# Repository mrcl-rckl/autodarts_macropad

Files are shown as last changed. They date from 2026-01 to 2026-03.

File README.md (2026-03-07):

<div align="center">
    3D-Modell
  
  <h1>🎯 Macropad for Autodarts</h1>
  <p><b>✨ The ultimate DIY wireless companion for your Autodarts setup ✨</b></p>
  <p><i>A custom 12-key controller designed for seamless darts tracking.</i></p>

  <p>
    The Macropad for Autodarts is a wireless DIY controller featuring 12 mechanical keys, specifically designed for comfortable operation of the Autodarts software directly from the oche. It provides instant access to functions such as undoing throws, switching cameras, triggering chat macros, or calling the AI referee. Utilizing smart ZMK firmware, it features multi-tap functions and dedicated correction layers optimized for the Autodarts Tools extension, while offering an impressive battery life of about six weeks via Bluetooth.
  </p>

  <p>
    
    
    
  </p>

  <p>
    <a href="#features-en">🚀 Features</a> •
    <a href="#manual-en">📖 Manual</a> •
    <a href="#diagrams-en">🗺️ Wiring & Pinout</a> •
    <a href="#keymap-en">🎹 Keymap & Layers</a> •
    <a href="#bom-en">📦 BOM</a> •
    <a href="#operation-en">💡 Troubleshooting</a> •
    <a href="#support-en">☕ Support</a>
  </p>
</div>

<hr />

<h2 id="features-en">🚀 Key Features</h2>
<ul>
  <li><b>📶 True Wireless:</b> Low-energy Bluetooth 5.0 connectivity via the nRF52840 controller for a cable-free oche. 🎯</li>
  <li><b>🔋 Massive Battery Life:</b> Operates for up to <b>6 weeks</b> on a single charge. The integrated deep-sleep mode further preserves battery life. ⚡</li>
  <li><b>🧠 Smart ZMK Layers:</b> Features tap-dance capabilities (e.g., single tap for correction, double tap for camera switch) to map far more than 12 functions to the board.</li>
  <li><b>🔢 Autodarts Tools Integration:</b> A dedicated numpad layer instantly activates for score corrections, sends your input, and automatically snaps back to your game layout. </li>
  <li><b>⌨️ Superior Tactile Feedback:</b> 12 mechanical Gateron G Pro 3.0 switches provide a high-quality actuation point for reliable inputs. ⌨️</li>
  <li><b>☁️ Cloud Configuration:</b> Customize your keymap directly in the browser via GitHub Actions—no local coding environment required. ☁️</li>
</ul>

<hr />

<h2 id="manual-en">📖 Comprehensive Manual</h2>
<p>
  This repository includes a <b>detailed 32-page PDF instruction manual</b>. It covers the entire process: from optimized 3D printing settings and complex matrix soldering to flashing the ZMK firmware and customized key mapping.
  <br><br>
  👉 <b>View the Instructions here:</b> <a href="https://github.com/mrcl-rckl/autodarts_macropad/blob/main/instructions/0_EN_Instructions.pdf">0_EN_Instructions.pdf</a>
  <br>
  👉 <b>3D Models on Printables:</b> <a href="https://www.printables.com/model/1576041-autodarts-macropad">Printables.com</a>
  <br>
  👉 <b>3D Models on MakerWorld:</b> <a href="https://makerworld.com/de/models/2319788-autodarts-macropad">MakerWorld.com</a>
</p>

<hr />

<h2 id="bom-en">📦 Bill of Materials (BOM)</h2>
<p>This project is designed for experienced makers and involves 3D printing, component assembly, and precision soldering. 🛠️</p>
<table>
  <thead>
    <tr>
      <th>Qty</th>
      <th>Component 🛒</th>
      <th>Source 🔗</th>
    </tr>
  </thead>
  <tbody>
    <tr>
      <td>12x</td>
      <td><b>Gateron G Pro 3.0 Switches</b></td>
      <td><a href="https://de.aliexpress.com/item/1005007052507996.html">AliExpress</a></td>
    </tr>
    <tr>
      <td>1x</td>
      <td><b>nRF52840 Developer Board (SuperMini)</b></td>
      <td><a href="https://de.aliexpress.com/item/1005008664621573.html">AliExpress</a></td>
    </tr>
    <tr>
      <td>1x</td>
      <td><b>500mAh LiPo Battery (503030)</b></td>
      <td><a href="https://de.aliexpress.com/item/1005007964712378.html">AliExpress</a></td>
    </tr>
    <tr>
      <td>12x</td>
      <td><b>1N4148 Diodes</b></td>
      <td><a href="https://de.aliexpress.com/item/1005006208000285.html">AliExpress</a></td>
    </tr>
    <tr>
      <td>16x</td>
      <td><b>Jumper Wires Female (20-30cm)</b></td>
      <td><a href="https://de.aliexpress.com/item/1005007046465880.html">AliExpress</a></td>
    </tr>
    <tr>
      <td>1x</td>
      <td><b>Toggle Switch (MTS-101)</b></td>
      <td><a href="https://de.aliexpress.com/item/1005009744920784.html">AliExpress</a></td>
    </tr>
    <tr>
      <td>1x</td>
      <td><b>ASUS USB-BT500 Bluetooth Dongle</b></td>
      <td><a href="https://www.cyberport.de/pc-und-zubehoer/netzwerk/bluetooth/asus/pdp/4e18-007/asus-usb-bt500-bluetooth-5-0-usb-adapter.html">Cyberport</a></td>
    </tr>
  </tbody>
</table>

<h3>🛠️ Required Tools & Additional Materials</h3>
<ul>
  <li>USB-C charging cable</li>
  <li>Soldering iron & Solder wire</li>
  <li>Hot air gun or lighter (for insulation)</li>
  <li>Heat shrinks & side cutters</li>
  <li>Pliers & wire stripping tool</li>
  <li>Super glue (for mounting logos)</li>
  <li>Filament (PLA or PETG - 2 colors recommended)</li>
</ul>

<hr />

<h2 id="diagrams-en">🗺️ Wiring Diagram & Pinout</h2>
<div align="center">
  <h3>🛠️ Wiring Diagram</h3>
  Wiring Diagram
  <br><br>
  <h3>🔌 Controller Pinout</h3>
  Pin Diagram
</div>

<hr />

<h2 id="keymap-en">🎹 Default Key Assignment & Layers</h2>
<p>The layout is fully optimized for the Autodarts web interface commands. Through smart ZMK firmware programming, the 12 physical keys access three different functional layers: 🎯</p>

<ul>
  <li><b>Layer 0 (Main):</b> Game controls (Start/Stop, Refresh, AI, Undo, Next, Mouse Click). Multi-tap keys let you send chat macros (tap vs. double-tap). Bottom row selects a dart for correction (1x tap) or switches cameras (2x tap).</li>
  <li><b>Layer 1 (Admin/BT):</b> Activated by double-tapping <b>Undo + Next</b> simultaneously. Stays active for 5 seconds to switch/clear Bluetooth profiles, restart, or enter bootloader mode.</li>
  <li><b>Layer 2 (Numpad):</b> Opens automatically when selecting a dart. Matches the <i>Autodarts Tools</i> extension numpad (1-9, Miss, 25, Bull). <b>Smart Exit:</b> Tapping any score automatically returns you to Layer 0. Holding any key for 1 second cancels the correction and returns to Layer 0 without sending a score.</li>
</ul>

<div align="center">
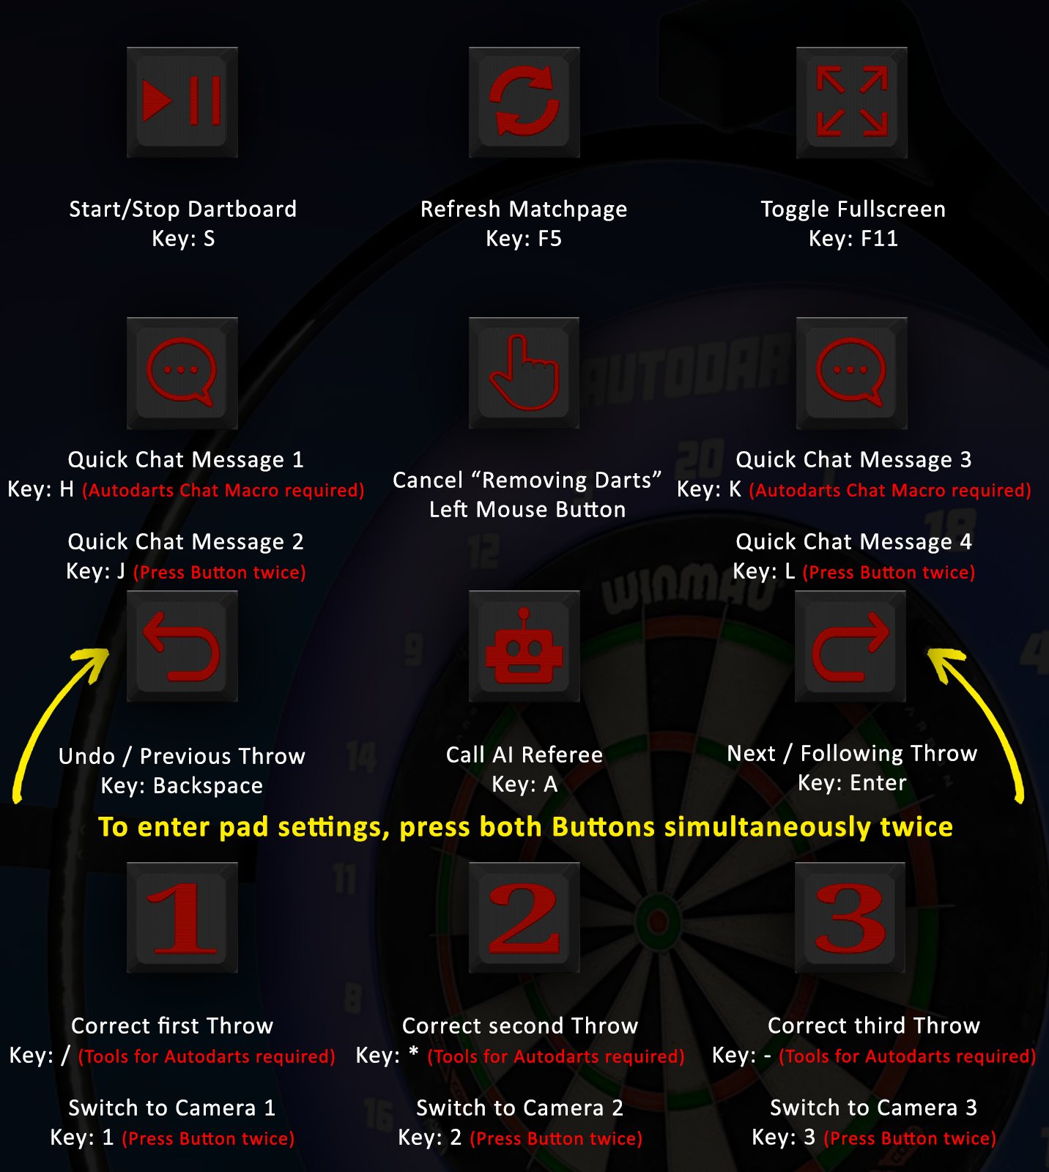
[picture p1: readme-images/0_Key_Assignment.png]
Keymap Assignment
  
</div>

<div align="center">
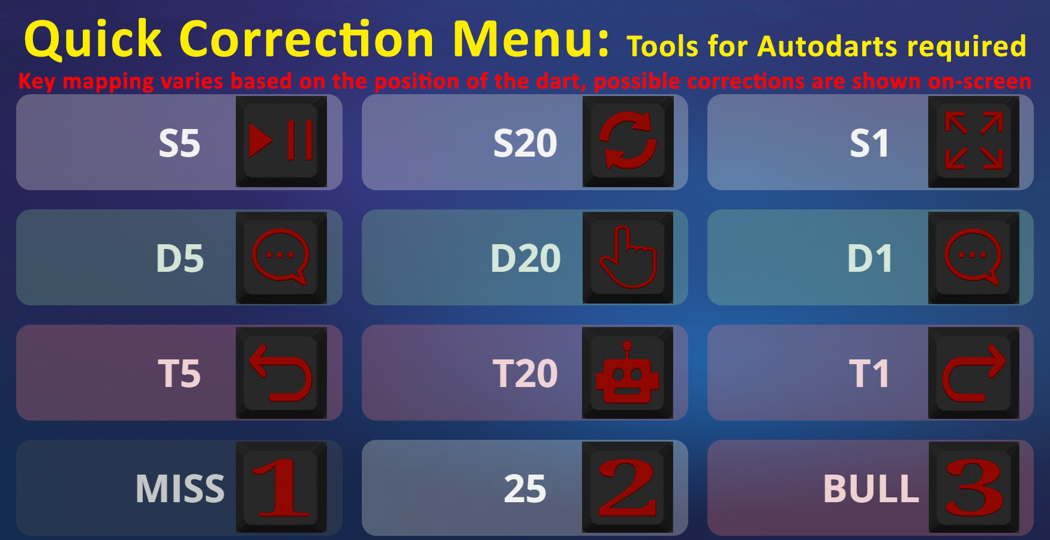
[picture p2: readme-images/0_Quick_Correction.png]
Quick Correction
  
</div>

<div align="center">
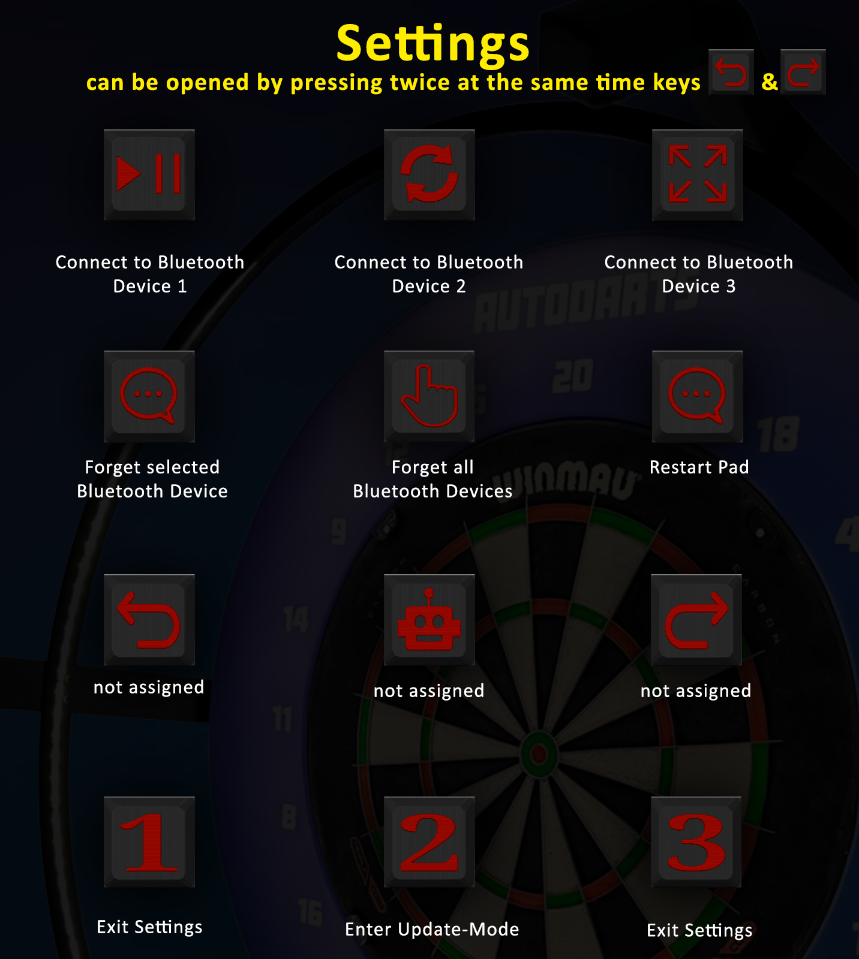
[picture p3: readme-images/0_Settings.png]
Settings
  
</div>

<br>

<hr />

<h2 id="operation-en">💡 Operation & Troubleshooting</h2>
<ul>
  <li><b>Charging:</b> The physical toggle switch <b>MUST be in the ON position</b> to charge the battery via USB-C. 🔌</li>
  <li><b>Admin Mode & Bluetooth:</b> To switch or clear Bluetooth profiles, double-tap <b>[Undo] + [Next]</b> simultaneously to enter the Admin Layer (active for 5s). 🔄</li>
  <li><b>Cancel Correction:</b> If you accidentally enter the Numpad layer, press and hold ANY key for 1 second to cancel and return to your game. 🔙</li>
  <li><b>Bootloader Mode:</b> If the software bootloader command fails, bridge the <b>GND</b> and <b>RST</b> pins twice quickly with tweezers while connected to the PC to flash a new firmware. 💾</li>
  <li><b>Input Focus:</b> Ensure the browser window is "in focus" (clicked) for Autodarts to register key presses. 🎯</li>
</ul>

<hr />

<h2 id="support-en">☕ Support</h2>
<p align="left">
  If this project helped you hit the bullseye, consider supporting my work! 🎯☕
  <br><br>
  <a href="https://www.buymeacoffee.com/mrcl_rckl">
    Buy Me A Coffee
  </a>
</p>

<hr />
<br><br>

<br><br>
<hr />

<div align="center">
  <h1>🎯 Zusatztastatur für Autodarts</h1>
  <p><b>✨ Der ultimative kabellose Begleiter für dein Autodarts-Setup – Marke Eigenbau ✨</b></p>
  <p><i>Ein maßgeschneidertes 12-Tasten-Steuergerät für die professionelle Wurferfassung am Oche.</i></p>

  <p>
    Das Macropad für Autodarts ist ein kabelloses DIY-Steuergerät mit 12 mechanischen Tasten, das speziell für die komfortable Bedienung der Autodarts-Software direkt am Oche entwickelt wurde. Es ermöglicht den blitzschnellen Zugriff auf Funktionen wie Wurfrücknahme, Kamerawechsel, Chat-Makros oder den KI-Schiedsrichter. Dank intelligenter ZMK-Firmware bietet das Pad smarte Mehrfachklick-Funktionen sowie eine perfekt auf die Autodarts Tools angepasste Numpad-Ebene und erreicht dabei über Bluetooth eine beachtliche Akkulaufzeit von etwa sechs Wochen.
  </p>

  <p>
    
    
    
  </p>

  <p>
    <a href="#features-de">🚀 Funktionen</a> •
    <a href="#manual-de">📖 Anleitung</a> •
    <a href="#diagrams-de">🗺️ Schaltplan & Pinbelegung</a> •
    <a href="#keymap-de">🎹 Tastenbelegung & Ebenen</a> •
    <a href="#bom-de">📦 Stückliste</a> •
    <a href="#operation-de">💡 Fehlerbehebung</a> •
    <a href="#support-de">☕ Unterstützung</a>
  </p>
</div>

<hr />

<h2 id="features-de">🚀 Hauptmerkmale</h2>
<ul>
  <li><b>📶 Vollkommen Kabellos:</b> Dank Bluetooth 5.0 und dem nRF52840-Steuermodul bleibt dein Abwurfbereich frei von Kabeln. 🎯</li>
  <li><b>🔋 Enorme Akkulaufzeit:</b> Eine einzige Ladung hält bei normaler Nutzung bis zu <b>6 Wochen</b>. Der integrierte Tiefschlafmodus schont die Batterie zusätzlich. ⚡</li>
  <li><b>🧠 Smarte ZMK-Ebenen:</b> Dank Tap-Dance-Funktion (z.B. 1x Tippen für Dart-Korrektur, 2x Tippen für Kamerawechsel) lassen sich weit mehr als 12 Funktionen steuern.</li>
  <li><b>🔢 Autodarts Tools Integration:</b> Eine spezielle Numpad-Ebene für die Erweiterung öffnet sich automatisch, sendet den gewählten Score und springt selbstständig ins Hauptmenü zurück.</li>
  <li><b>⌨️ Hochwertiger Druckpunkt:</b> 12 mechanische Gateron G Pro 3.0 Schalter bieten ein erstklassiges haptisches Feedback und garantieren eine zuverlässige Bedienung. ⌨️</li>
  <li><b>☁️ Cloud-Konfiguration:</b> Die Tastenbelegung kann direkt im Browser über GitHub-Automatisierungen angepasst werden – es ist keine lokale Programmierumgebung erforderlich. ☁️</li>
</ul>

<hr />

<h2 id="manual-de">📖 Umfangreiche Anleitung</h2>
<p>
  In diesem Projektarchiv findest du eine <b>detaillierte 32-seitige PDF-Anleitung</b>. Diese führt dich Schritt für Schritt durch den gesamten Prozess: von den optimalen Einstellungen für den 3D-Druck über das präzise Verlöten der Tastatur-Matrix bis hin zur Installation der Steuersoftware und der persönlichen Tastenbelegung.
  <br><br>
  👉 <b>Hier zur Anleitung:</b> <a href="https://github.com/mrcl-rckl/autodarts_macropad/blob/main/instructions/0_DE_Anleitung.pdf">0_DE_Anleitung.pdf</a>
  <br>
  👉 <b>3D-Modelle auf Printables:</b> <a href="https://www.printables.com/model/1576041-autodarts-macropad">Printables.com</a>
  <br>
  👉 <b>3D-Modelle auf MakerWorld:</b> <a href="https://makerworld.com/de/models/2319788-autodarts-macropad">MakerWorld.com</a>
</p>

<hr />

<h2 id="bom-de">📦 Stückliste</h2>
<p>Dieses Projekt wird für erfahrene Bastler empfohlen, da es fundierte Kenntnisse im 3D-Druck und im Weichlöten voraussetzt. 🛠️</p>
<table>
  <thead>
    <tr>
      <th>Menge</th>
      <th>Bauteil 🛒</th>
      <th>Bezugsquelle 🔗</th>
    </tr>
  </thead>
  <tbody>
    <tr>
      <td>12x</td>
      <td><b>Gateron G Pro 3.0 Tastenschalter</b></td>
      <td><a href="https://de.aliexpress.com/item/1005007052507996.html">AliExpress</a></td>
    </tr>
    <tr>
      <td>1x</td>
      <td><b>nRF52840 Entwickler-Platine (SuperMini)</b></td>
      <td><a href="https://de.aliexpress.com/item/1005008664621573.html">AliExpress</a></td>
    </tr>
    <tr>
      <td>1x</td>
      <td><b>500mAh LiPo Akku (Bauform 503030)</b></td>
      <td><a href="https://de.aliexpress.com/item/1005007964712378.html">AliExpress</a></td>
    </tr>
    <tr>
      <td>12x</td>
      <td><b>1N4148 Dioden</b></td>
      <td><a href="https://de.aliexpress.com/item/1005006208000285.html">AliExpress</a></td>
    </tr>
    <tr>
      <td>16x</td>
      <td><b>Steckbrückenkabel (weiblich, 20-30cm)</b></td>
      <td><a href="https://de.aliexpress.com/item/1005007046465880.html">AliExpress</a></td>
    </tr>
    <tr>
      <td>1x</td>
      <td><b>Kippschalter (MTS-101)</b></td>
      <td><a href="https://de.aliexpress.com/item/1005009744920784.html">AliExpress</a></td>
    </tr>
    <tr>
      <td>1x</td>
      <td><b>ASUS USB-BT500 Bluetooth-Adapter</b></td>
      <td><a href="https://www.cyberport.de/pc-und-zubehoer/netzwerk/bluetooth/asus/pdp/4e18-007/asus-usb-bt500-bluetooth-5-0-usb-adapter.html">Cyberport</a></td>
    </tr>
  </tbody>
</table>

<h3>🛠️ Erforderliche Werkzeuge & Materialien</h3>
<ul>
  <li>USB-C Ladekabel</li>
  <li>Lötkolben & Lötzinn</li>
  <li>Heißluftfön oder Feuerzeug (für die Isolierung der Kontakte)</li>
  <li>Schrumpfschläuche & Seitenschneider</li>
  <li>Zange & Abisolierwerkzeug</li>
  <li>Sekundenkleber (zum Fixieren der Logos)</li>
  <li>Filament (PLA oder PETG - 2 verschiedene Farben für Kontrast-Optik empfohlen)</li>
</ul>

<hr />

<h2 id="diagrams-de">🗺️ Stromlaufplan & Anschlussbelegung</h2>
<div align="center">
  <h3>🛠️ Schaltplan der Tastatur-Matrix</h3>
  Stromlaufplan
  <br><br>
  <h3>🔌 Anschlussbelegung des Steuerungsmoduls</h3>
  Anschlussbelegung
</div>

<hr />

<h2 id="keymap-de">🎹 Tastenbelegung & Ebenen (Layers)</h2>
<p>Die Tasten sind für die Autodarts-Weboberfläche optimiert. Durch smarte ZMK-Programmierung verbergen sich hinter den 12 physischen Tasten drei Funktionsebenen: 🎯</p>

<ul>
  <li><b>Ebene 0 (Hauptmodus):</b> Spielsteuerung (Start/Stop, Maus, KI, Undo, Next). Die mittleren Tasten rufen je nach Tippfrequenz Chat-Makros auf. Die unterste Reihe wählt bei einfachem Klick Darts zur Korrektur aus, beim Doppelklick werden die Kameras umgeschaltet.</li>
  <li><b>Ebene 1 (Admin/BT):</b> Wird aktiviert durch den zeitgleichen Doppelklick auf <b>Undo + Next</b> (die äußeren Tasten in Reihe 3). Bleibt für 5 Sekunden aktiv, um Bluetooth-Profile zu wechseln, zu löschen oder die Tastatur neu zu starten.</li>
  <li><b>Ebene 2 (Numpad):</b> Öffnet sich automatisch bei der Dart-Auswahl. Das Layout entspricht exakt der <i>Autodarts Tools</i> Erweiterung (1-9, Miss, 25, Bull). <b>Smart Exit:</b> Nach dem Eintippen eines Scores schließt sich das Numpad automatisch. Hältst du eine beliebige Taste für 1 Sekunde gedrückt, brichst du den Vorgang ab und gelangst ohne Eingabe ins Spiel zurück.</li>
</ul>

<div align="center">
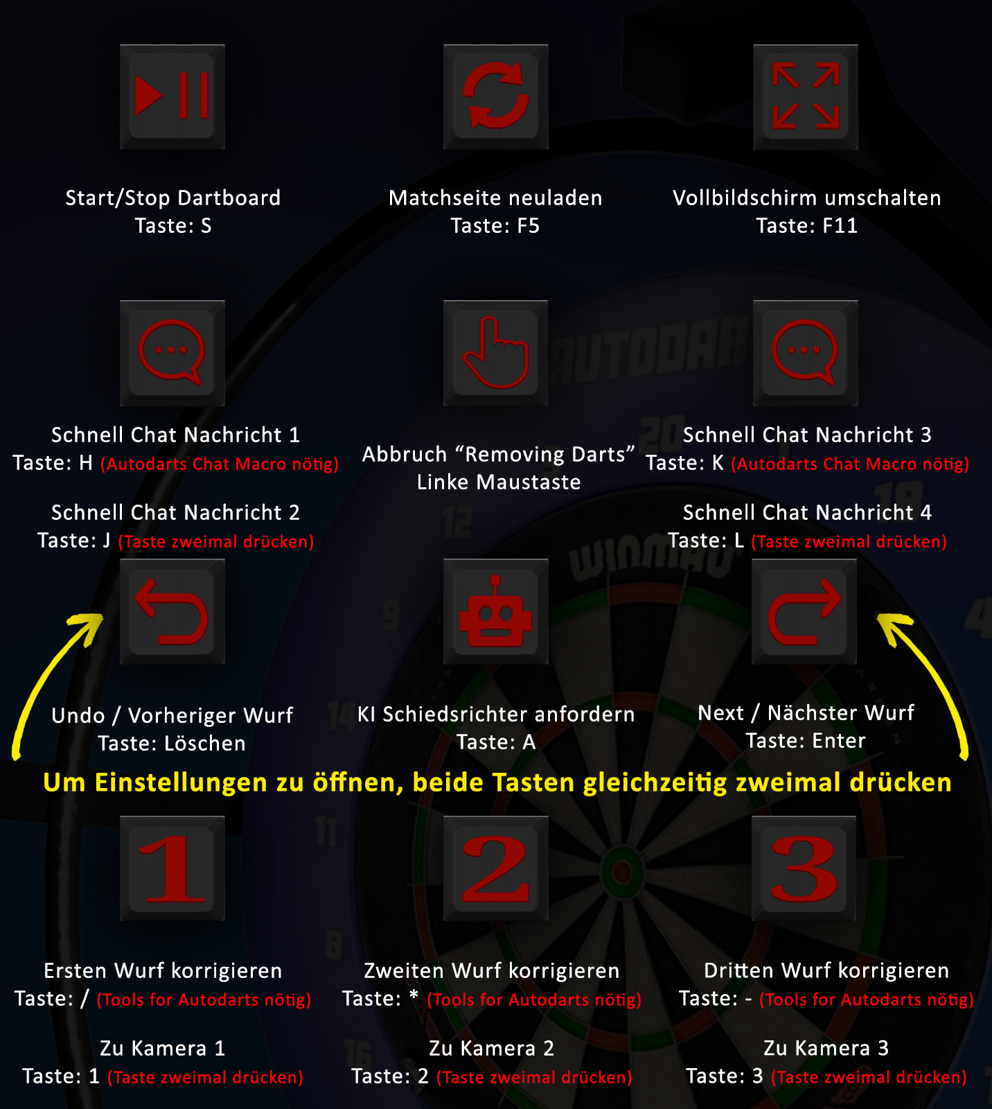
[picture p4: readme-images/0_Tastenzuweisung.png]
Tastenbelegung
  
</div>

<div align="center">
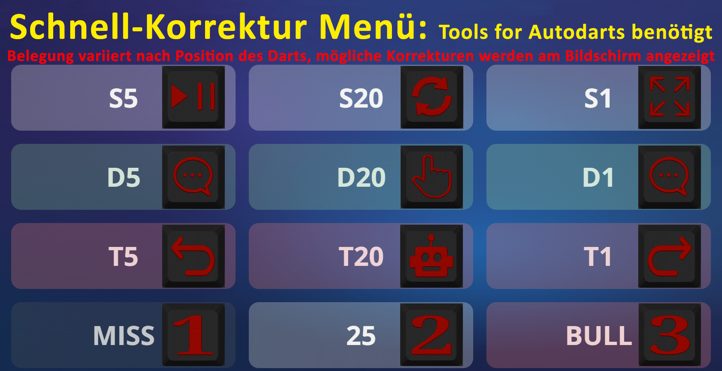
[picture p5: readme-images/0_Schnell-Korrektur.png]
Schnell-Korrekur
  
</div>

<div align="center">
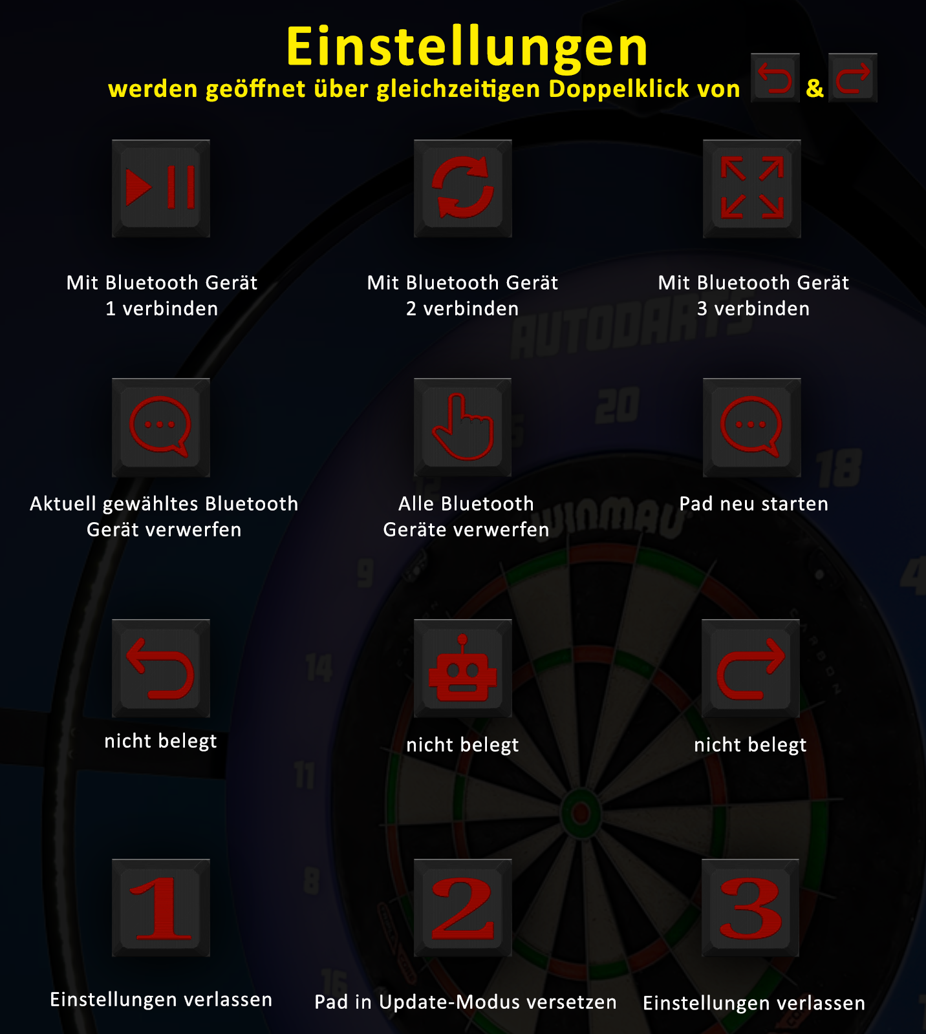
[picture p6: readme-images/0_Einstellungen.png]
Einstellungen
  
</div>

<br>

<hr />

<h2 id="operation-de">💡 Bedienung & Fehlerbehebung</h2>
<ul>
  <li><b>Ladevorgang:</b> Der physische Kippschalter <b>MUSS auf EIN (ON)</b> stehen, damit der Akku über USB-C geladen werden kann. 🔌</li>
  <li><b>Admin-Modus & Bluetooth:</b> Um Bluetooth-Profile zu löschen oder zu wechseln, tippe <b>[Undo] + [Next]</b> zweimal schnell gleichzeitig (Doppelklick), um für 5 Sekunden in die Admin-Ebene zu wechseln. 🔄</li>
  <li><b>Korrektur abbrechen:</b> Bist du aus Versehen im Numpad-Modus gelandet, halte eine BELIEBIGE Taste für 1 Sekunde gedrückt. Das Pad bricht ab und wirft dich ins Standard-Layout zurück. 🔙</li>
  <li><b>Bootloader-Modus (Flashen):</b> Falls sich die Tastatur über die Software nicht in den Flash-Modus versetzen lässt, überbrücke am angeschlossenen Pad kurz zweimal hintereinander die Kontakte <b>GND</b> und <b>RST</b> mit einer Pinzette. 💾</li>
  <li><b>Eingabe-Fokus:</b> Das Browserfenster muss aktiv sein („im Fokus“), damit Autodarts die Tastaturbefehle registriert. 🎯</li>
</ul>

<hr />

<h2 id="support-de">☕ Unterstützung</h2>
<p align="left">
  Hat dieses Projekt bei dir ins Schwarze getroffen? Wenn du meine Arbeit unterstützen möchtest, freue ich mich über einen digitalen Kaffee! Jeder Beitrag fließt direkt in die Entwicklung neuer Prototypen und quelloffener Werkzeuge für die Community. 🎯☕
  <br><br>
  <a href="https://www.buymeacoffee.com/mrcl_rckl">
    Spende mir einen Kaffee
  </a>
</p>

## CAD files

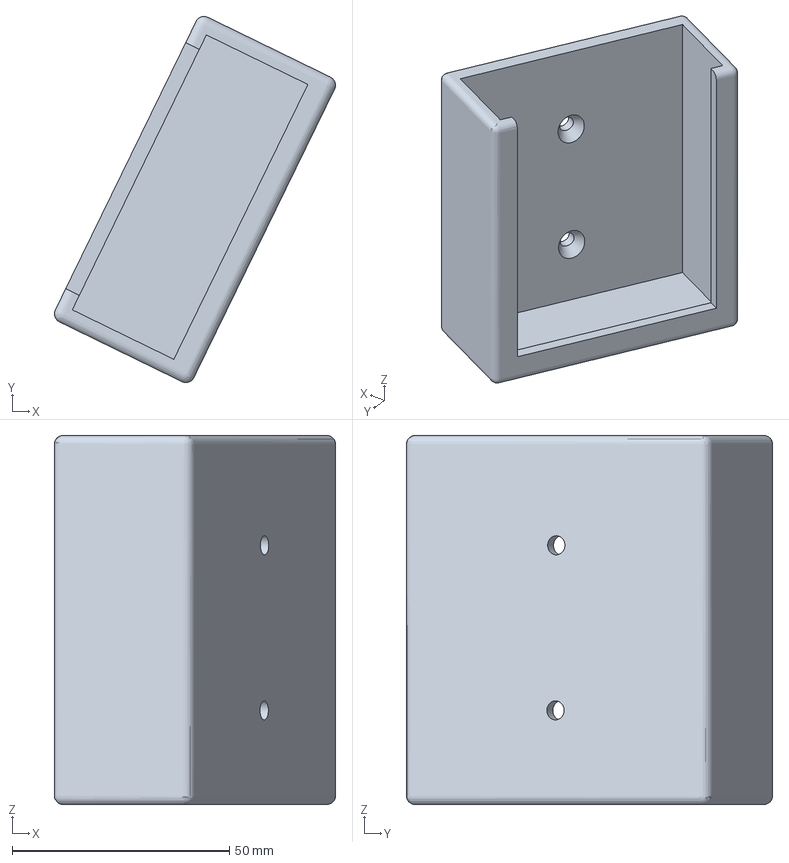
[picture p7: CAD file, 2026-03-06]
3d-printing-files/4_Mounting_(optional).3mf
64.7 x 84.3 x 85.0 mm

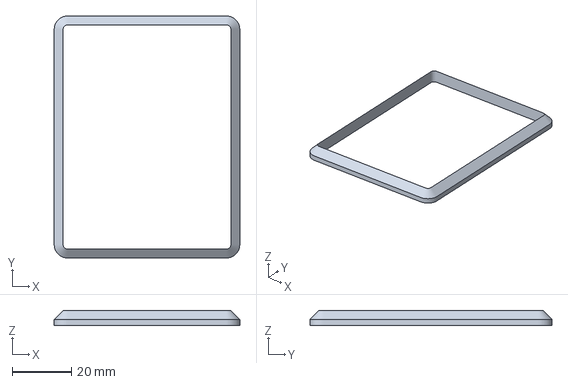
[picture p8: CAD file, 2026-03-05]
3d-printing-files/5_Frame.3mf
62.5 x 81.5 x 5.00 mm

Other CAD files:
3d-printing-files/4_Mounting_(optional).stl
3d-printing-files/5_Frame.stl

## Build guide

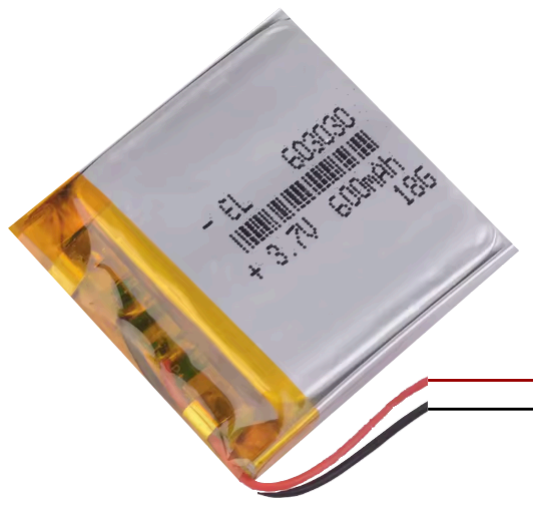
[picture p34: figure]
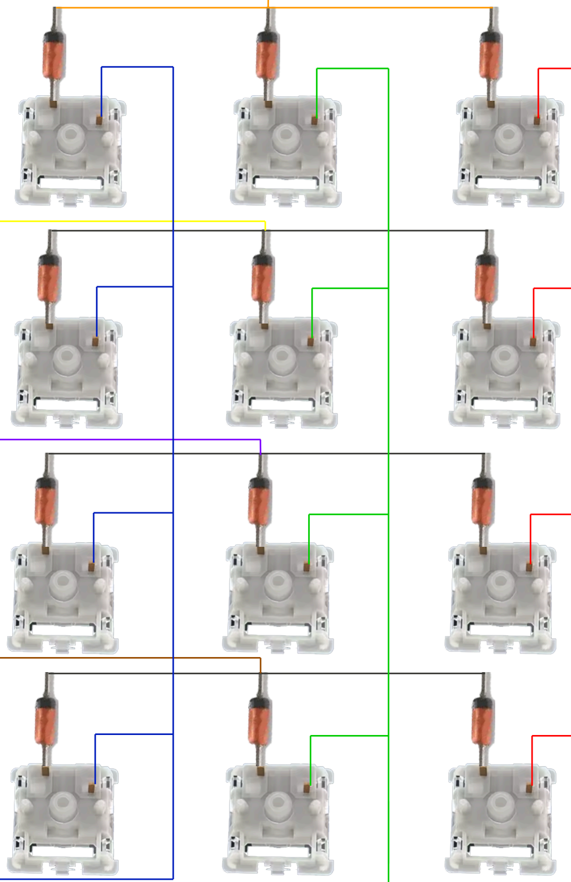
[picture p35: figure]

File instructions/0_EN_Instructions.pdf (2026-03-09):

English

Author: mrcl-rckl | 1 | Version: 1.0

# DIY: 12-button macro pad for autodarts

Difficulty: Recommended for experienced manufacturers

Requires 3D printing and soldering

Author: mrcl-rckl | 2 | Version: 1.0

# Table of Contents:

Page(s) | Contents
1 | Front page
2 | Table of Contents
3 | List of materials
4 | Tools and additional materials
5 | 3D printing
6-21 | Soldering and assembly
22-24 | Installation and Completion
25-27 | Testing
28-29 | Operating instructions
30-32 | Frequently Asked Questions
33 | Firmware customization
34 | Thank you!

Author: mrcl-rckl | 3 | Version: 1.0

# List of materials:

- 12x GATERON G Pro 3.0 Switches: https://de.aliexpress.com/item/1005007052507996.html
- 1x nRF52840 Developer Board (SuperMini): https://de.aliexpress.com/item/1005008664621573.html
- 1x 503030 500mAh battery (also larger possible, as there is enough space): https://de.aliexpress.com/item/1005007964712378.html
- 12x 1N4148 diodes:
https://de.aliexpress.com/item/1005006208000285.html
- 16x Jumper wires female (at least 20 cm → 30 cm recommended): https://de.aliexpress.com/item/1005007046465880.html
- 1x Toggle switch (not necessary, but recommended for longer battery life in standby): https://de.aliexpress.com/item/4001252480288.html
- 1x ASUS USB-BT500 Bluetooth 5.0 dongle adapter (not necessary if the device to be paired already has Bluetooth – but still recommended to save battery with BLE): https://www.cyberport.de/pc-undzubehoer/netzwerk/bluetooth/asus/pdp/4e18-007/asus-usb-bt500-bluetooth-5-0-usb-adapter.html (https://www.cyberport.de/pc-und-zubehoer/netzwerk/bluetooth/asus/pdp/4e18-007/asus-usb-bt500-bluetooth-5-0-usb-adapter.html)

Author: mrcl-rckl | 4 | Version: 1.0

# Required tools and additional materials:

- USB-C cable
- Solder
- Soldering iron
- Heat gun or lighter
- Heat Shrink Tubing
- Side Cutters
- Needle-nose pliers
- Stripping tool
- Superglue
- Filament – PLA or PETG or ... (2 different colors recommended)

Author: mrcl-rckl | 5 | Version: 1.0

# 3D printing:

Start by printing out all the models provided. If you're using a Bambu Lab printer, I recommend using the included .3mf files for better printing results.

To achieve a two-color print, a multi-color printer (with e.g. AMS). You can simply add a manual pause or a 'Filament Change' command to your slicer at the desired layer height. See: https://youtu.be/tKPWpWb8gBw. The printer will stop at the specified location, so you can swap the filament and resume printing.

To ensure the best print quality, you should not fill the printer with all models at the same time. I recommend grouping the prints as follows:

- Charge 1: Main case and the back
- Charge 2: All 12 keycaps (can be printed together)
- Charge 3: The optional wall mount should also be printed independently

Files on Printables: https://www.printables.com/model/1576041-autodartsmacropad (https://www.printables.com/model/1576041-autodarts-macropad)

Files on MakerWorld: https://makerworld.com/de/models/2319788-autodartsmacropad (https://makerworld.com/de/models/2319788-autodarts-macropad)

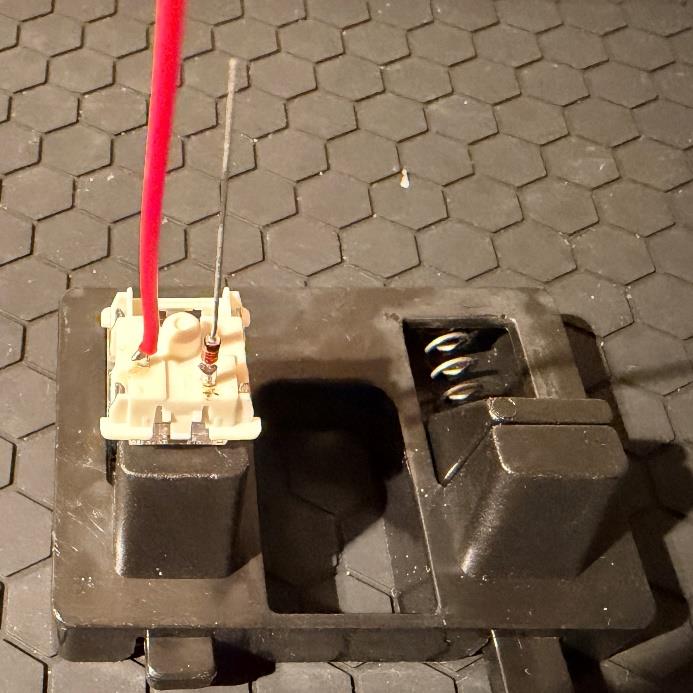
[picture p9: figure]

Author: mrcl-rckl | 6 | Version: 1.0

# Soldering and assembly:

1. For the first four buttons, start by soldering a 15 cm long red wire to one of the contact pins. A 1N4148 diode is soldered to the opposite pin. CRITICAL: Align the diode so that the black line points away from the key.
2. Snap the four pre-soldered keys into the housing vertically to form the first column. Make sure each key is tight.
3. For the next four buttons, start by soldering a 15 cm long green wire to one of the contact pins. A 1N4148 diode is soldered to the opposite pin. CRITICAL: Align the diode so that the black line points away from the key.

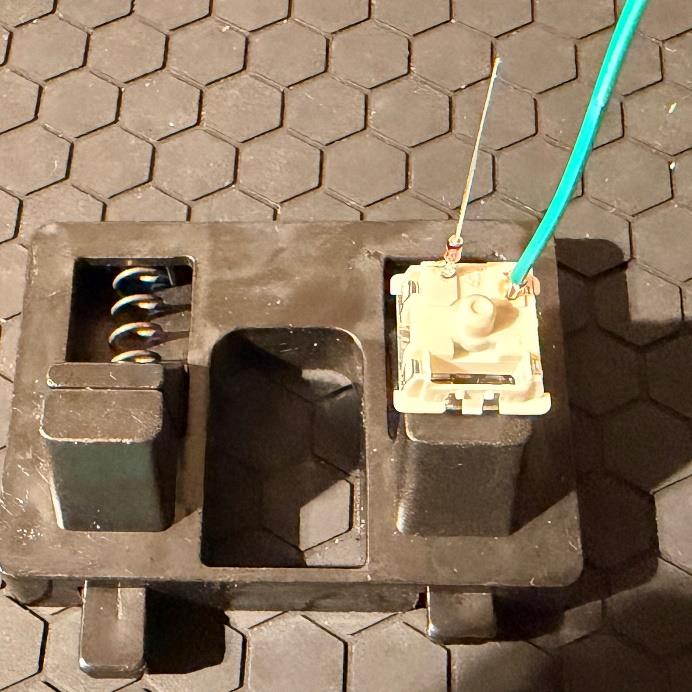
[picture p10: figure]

Author: mrcl-rckl | 7 | Version: 1.0
4. Snap the four pre-soldered buttons into the housing vertically to form the middle column. Make sure each key is tight.

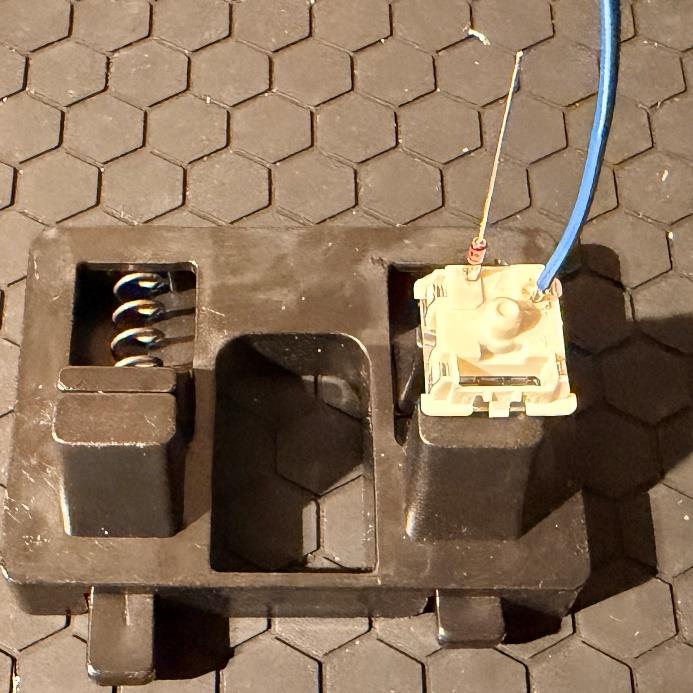
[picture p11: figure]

Author: mrcl-rckl | 8 | Version: 1.0
5. For the last four keys, start by soldering a 15 cm blue wire to one of the contact pins. A 1N4148 diode is soldered to the opposite pin.
CRITICAL: Align the diode so that the black line points away from the key.
6. Snap the four pre-soldered buttons into the housing vertically to form the last column. Make sure each key is tight.

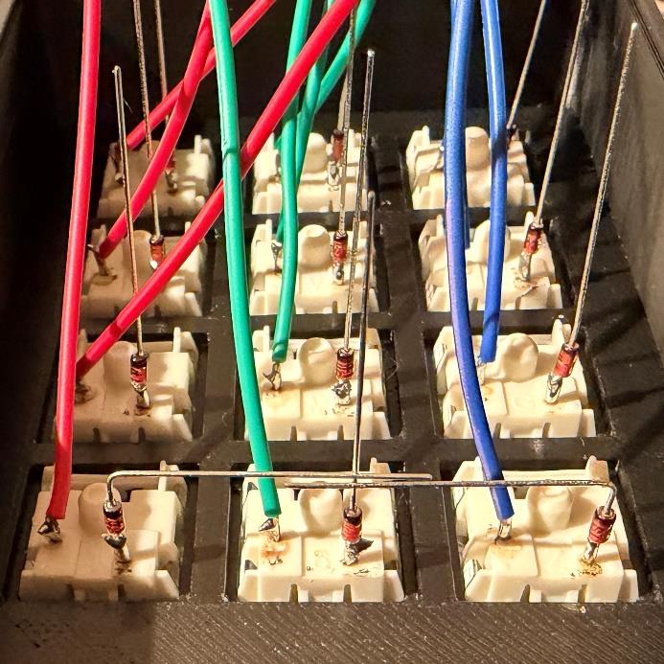
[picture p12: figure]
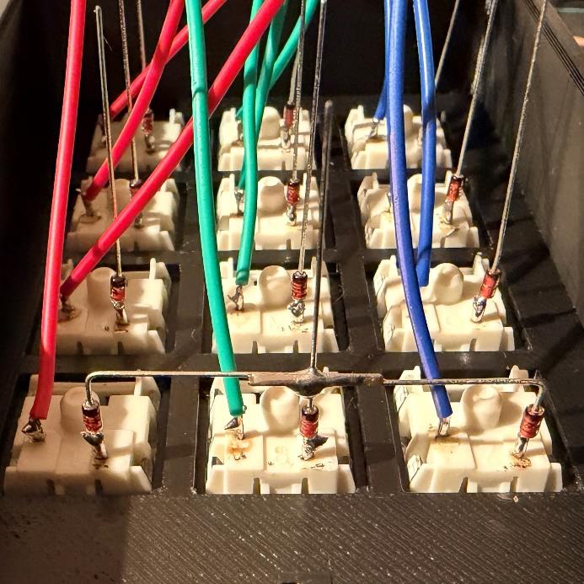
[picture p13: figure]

Author: mrcl-rckl | 9 | Version: 1.0
7. Identify the top row, indicated by the extra space reserved for the nRF52840. Bridge the three diodes by bending the outer terminals so that they overlap at the center diode. Using needle-nose pliers for this process ensures a more reliable bend.
8. Now solder the connection where the three cathode lines meet. Make sure the connection is clean and covers all three lines to create a reliable rowbus.

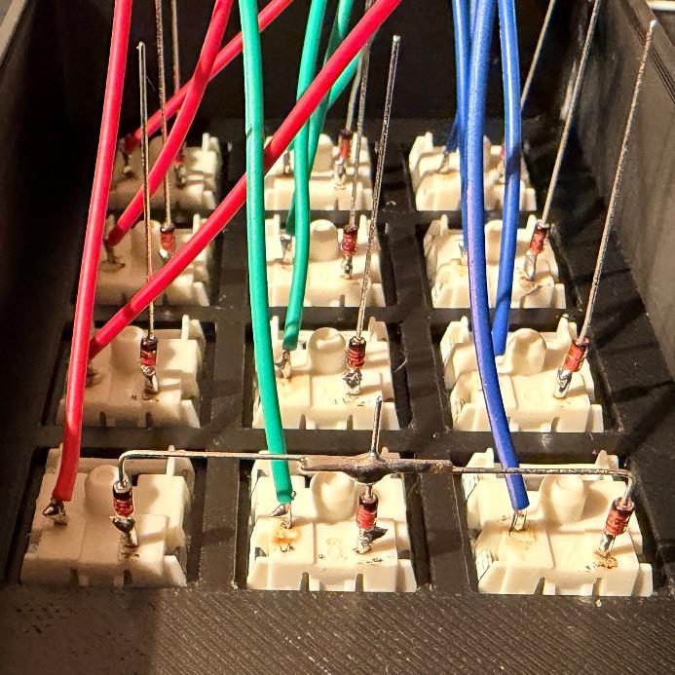
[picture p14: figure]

Author: mrcl-rckl | 10 | Version: 1.0
9. Use a side cutter to shorten the wire of the middle diode to about 8 mm in length. This leaves enough material for a secure connection for the next cable.
10. Solder a 20 cm orange cable with a female connector to the trimmed end of the diode. This cable serves as the main connection for your vertical row.

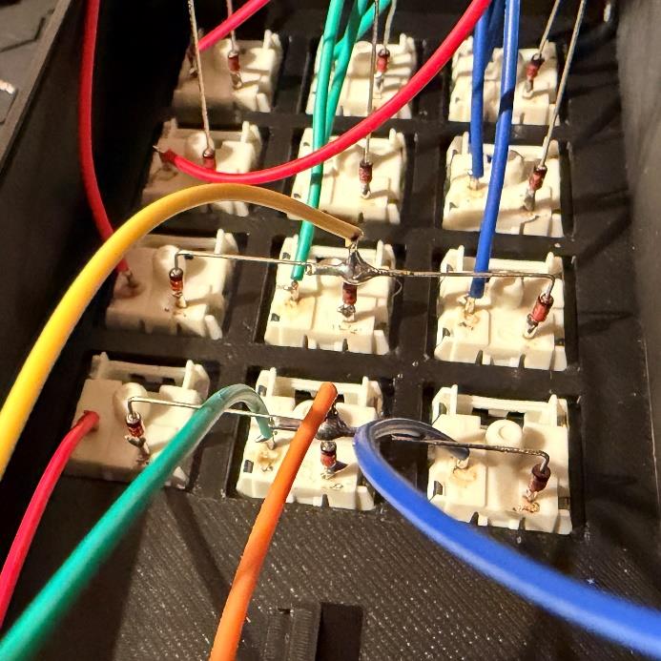
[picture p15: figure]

Author: mrcl-rckl | 11 | Version: 1.0
11. Repeat steps 7 through 10 for the second vertical column. However, replace the orange wire with a yellow wire. This color discrimination helps to correctly identify the rows during the final wiring phase.
12. Repeat steps 7 through 10 for the second vertical column. However, replace the orange wire with a purple wire. This color discrimination helps to correctly identify the rows during the final wiring phase.

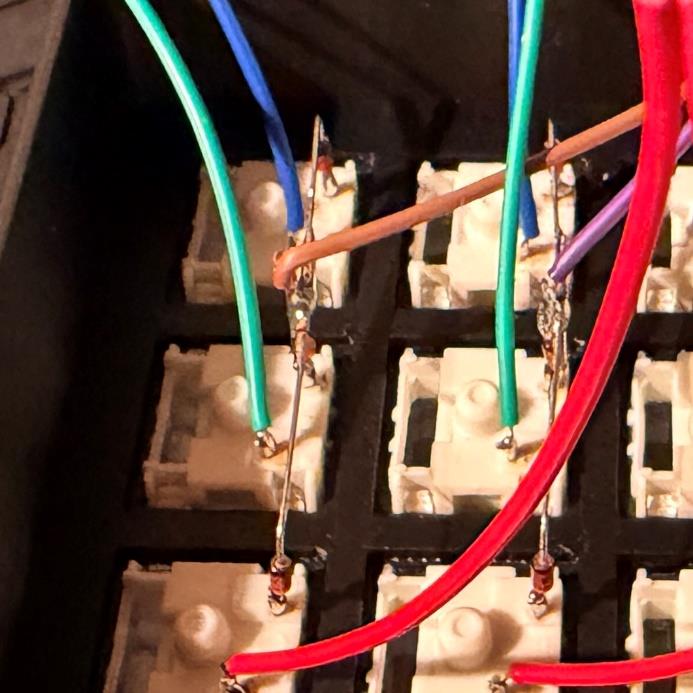
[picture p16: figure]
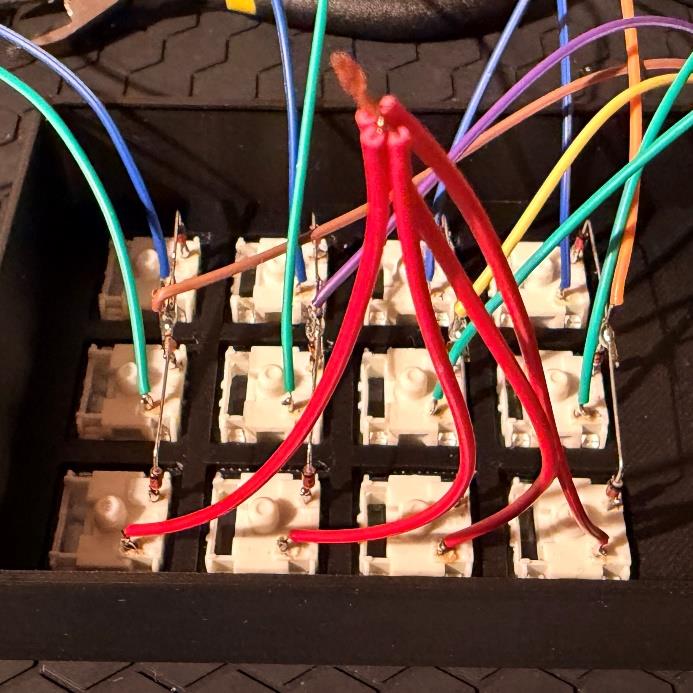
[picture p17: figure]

Author: mrcl-rckl | 12 | Version: 1.0
13. Repeat steps 7 through 10 for the second vertical column. However, replace the orange wire with a brown wire. This color discrimination helps to correctly identify the rows during the final wiring phase.
14. Strip off all the red wires and twist the ends of the copper strands together. Solder the bundle to create a single, secure termination point.

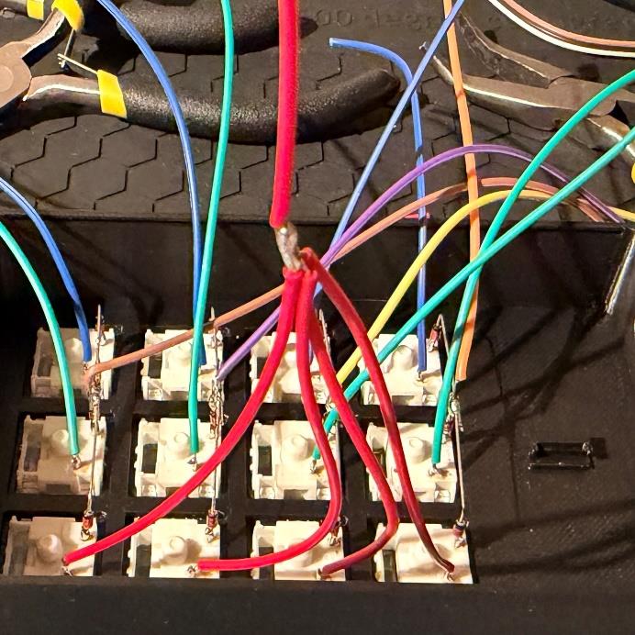
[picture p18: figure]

Author: mrcl-rckl | 13 | Version: 1.0
15. Prepare a 15 cm red cable with a female plug. Before soldering, slide a piece of heat shrink tubing onto the wire. Solder the open end of this cable to the red wire bundle you soldered in the previous step.
16. Slide the heat shrink tubing over the solder joint. Use a heat gun or lighter to shrink the hose until it forms a firm, secure seal around the joint.

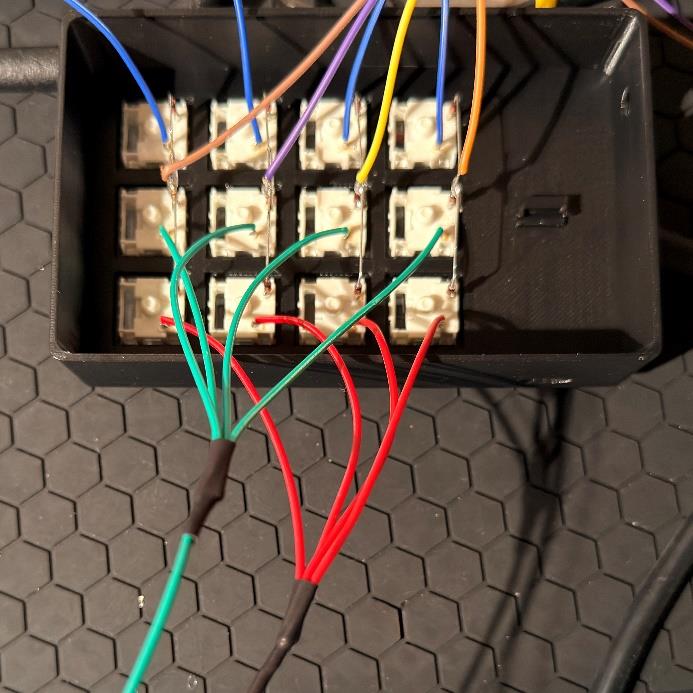
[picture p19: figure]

Author: mrcl-rckl | 14 | Version: 1.0
17. Repeat steps 14-16 with green wire instead of red for the middle column. Make sure that the solder joint is well insulated with heat shrink tubing as described earlier.
18. Repeat steps 14-16 with blue wire instead of red for the middle column. Make sure that the solder joint is well insulated with heat shrink tubing as described earlier.

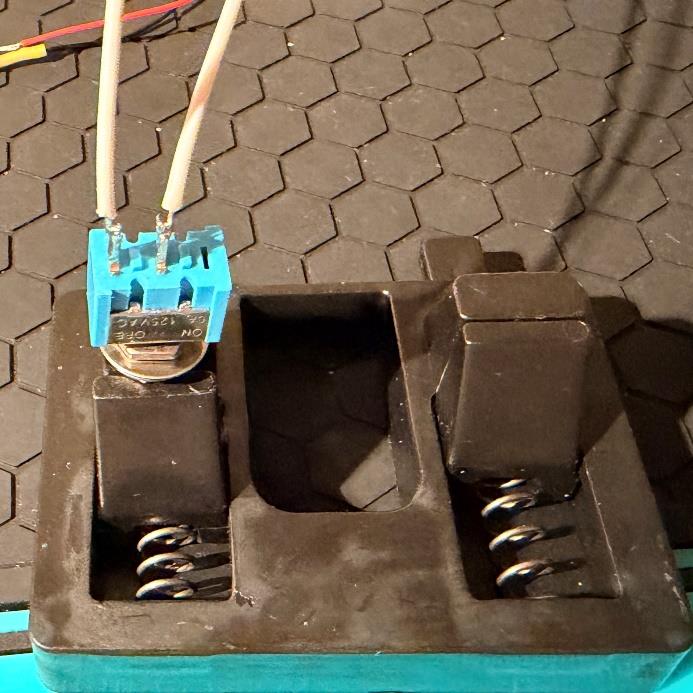
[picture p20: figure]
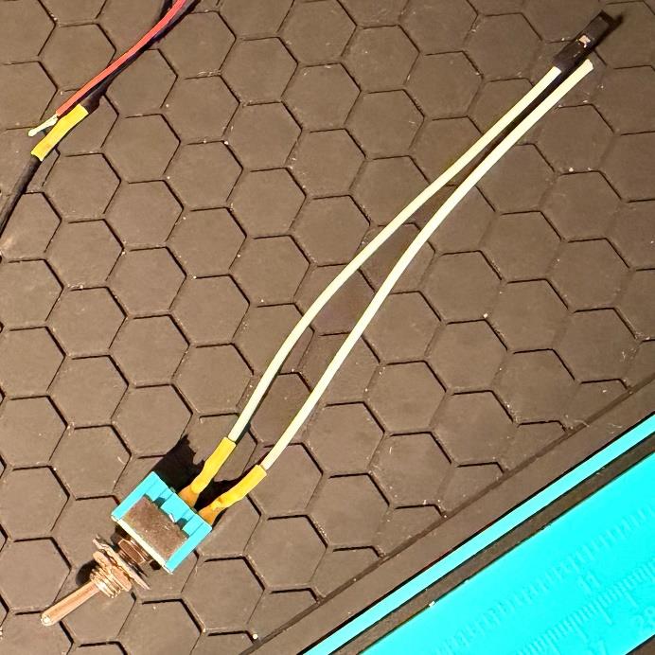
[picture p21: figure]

Author: mrcl-rckl | 15 | Version: 1.0
19. Prepare the toggle switch by cutting a 30 cm female cable in half. Remove a few millimeters of insulation from the cut ends and slide a piece of heat shrink tubing onto each wire. Solder the two wires to the toggle switch terminals.
20. Slide the hose over the solder joints and shrink them with a heat gun or lighter for a fully insulated connection.

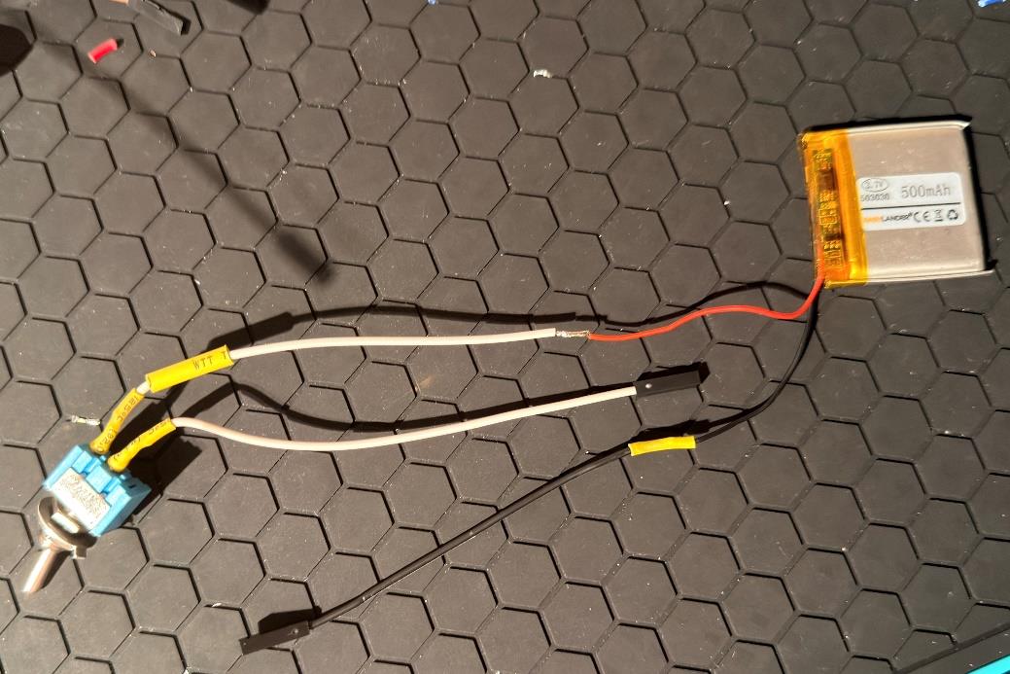
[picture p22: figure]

Author: mrcl-rckl | 16 | Version: 1.0

21.
a. Battery preparation: If your battery has a plug, cut it off. WARNING: Cut the wires one at a time to prevent a short circuit. Don't let the exposed ends touch each other!
b. Connect the toggle switch: Strip the ends of the red battery cable and the toggle switch cable. Slide a piece of heat shrink tubing onto the red (positive) cable of the battery, then solder it to the toggle switch wires.
c. Battery Ground Extension: Take a 15cm black female jumper cable. Remove the insulation at the end and do the same with the negative (black) line of the battery. Slide heat shrink tubing onto the cable before soldering. Connect the two black wires and solder them together to make a solid connection.
d. Insulation: Position both heat shrink tubing over the solder joints and shrink them with hot air or a lighter to completely insulate the joints.

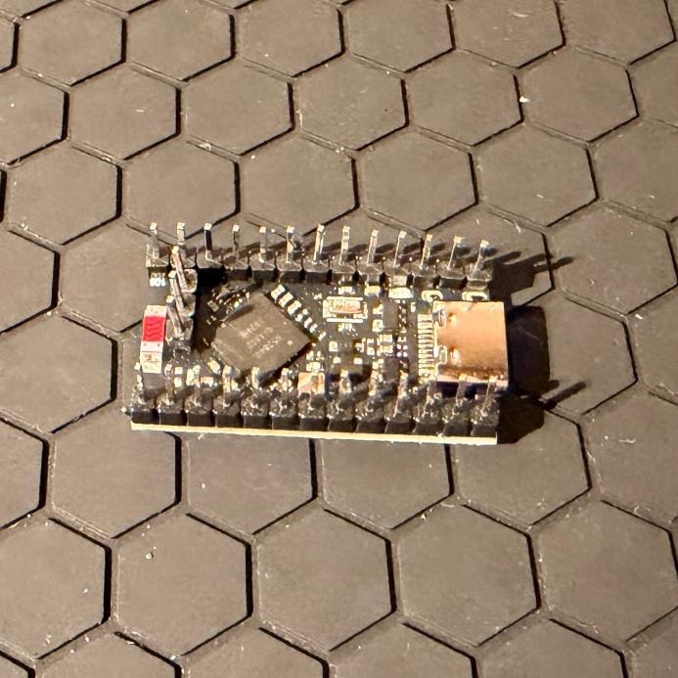
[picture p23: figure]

Author: mrcl-rckl | 17 | Version: 1.0
22. Unpack the microcontroller and solder the included male header pins to the board. Make sure the pins are perfectly vertical and the solder joints are clean, as these are the connection points for all of your female wires.
23. Place the controller in the case by aligning it with the two locking clips in the center of the case. You'll need to apply strong pressure near the USB-C port to slide the board down until the connector aligns perfectly with the case opening.
Note: You may need to move the controller carefully to find the perfect position. Be careful not to use excessive force so as not to damage the MCU or the 3D printed mounting tabs.

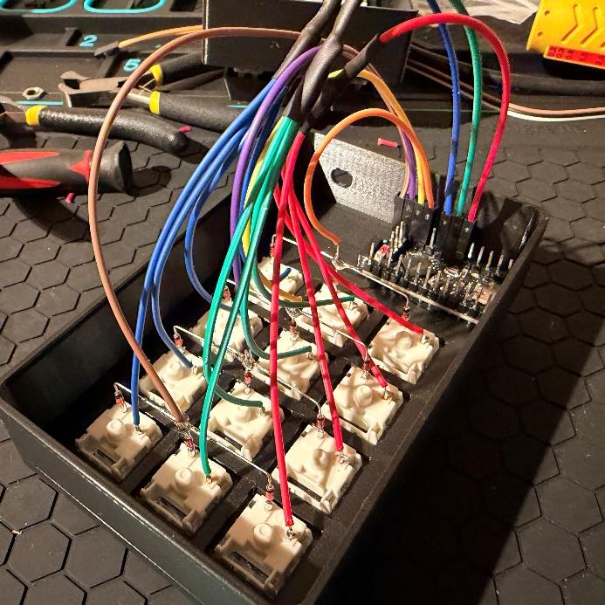
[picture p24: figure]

Author: mrcl-rckl | 18 | Version: 1.0
24. Now connect the female jumpers to the controller's header pins according to the schematic and pinout images provided.

Important: Double-check that each row and column line is connected to its assigned GPIO pin. A single reversed wire will result in incorrect button presses or an unresponsive matrix.

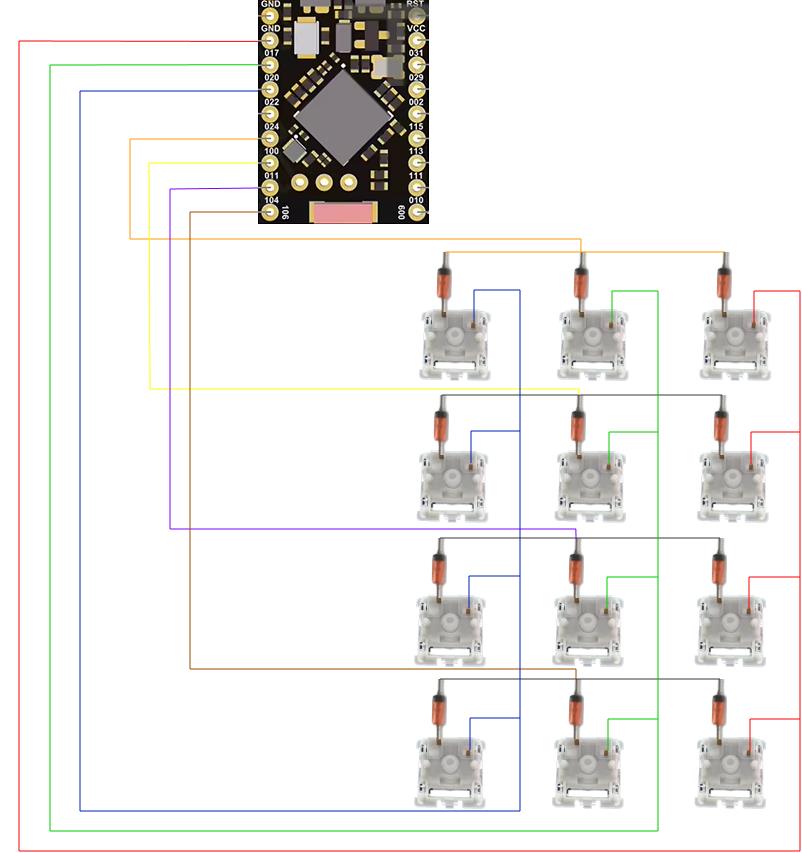
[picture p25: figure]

Author: mrcl-rckl | 19 | Version: 1.0

Author: mrcl-rckl | 20 | Version: 1.0
25. Install the toggle switch in the mounting hole provided in the case. Connect the female terminals (black and white) to the battery pads (B+ and B-) of the microcontroller, as shown in the reference image.
Important: Check the polarity before connecting. Swapping the battery lines may permanently damage the charging circuit of nRF52840.

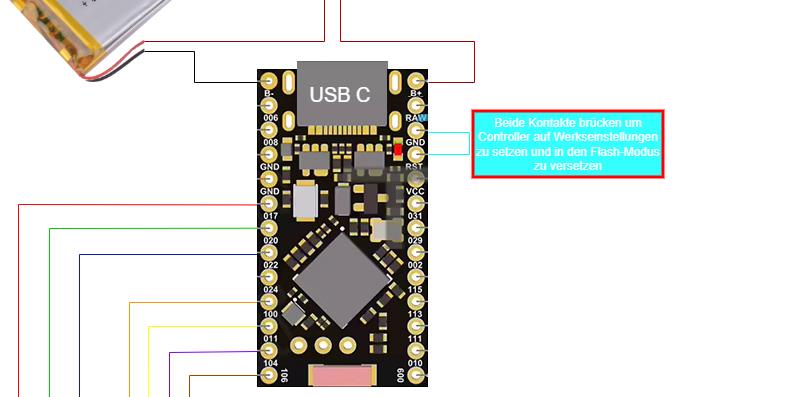
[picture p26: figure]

Author: mrcl-rckl | 21 | Version: 1.0

26.
a. Internal performance test: Toggle the toggle switch to ON. The onboard status LEDs should light up immediately.
b. USB connection: Turn off the switch and connect the controller to your computer via USB-C. The LEDs will come back on, and your PC should recognize the device as a drive (e.g., NICENANO). Troubleshooting: > If the drive doesn't appear, you may need to manually trigger bootloader mode: Connect the USB cable and make sure the power switch is OFF. Use a screwdriver or tweezers to gently bridge the GND and RST pins twice in a row.
CAUTION: Be extremely precise. Bridging the wrong pins could cause a short circuit and permanently damage the MCU.

Author: mrcl-rckl | 22 | Version: 1.0

27.
a. Install firmware: Simply drag the file 6_Macropad_Firmware.uf2 (download here: https://github.com/mrcl-rckl/autodarts_macropad/releases/download/Autodarts/6_Macropad_Firmware.uf2) (https://github.com/mrcl-rckl/autodarts_macropad/releases/download/Autodarts/6_Macropad_Firmware.uf2) onto the controller's drive.
b. Auto-restart: The MCU automatically flashes the firmware and reboots. The drive will disconnect and disappear from your computer. Note: To reflash in the future, you will need to manually switch back to bootloader mode by bridging GND and RST pins twice in a row.
c. Bluetooth pairing: Unplug the USB-C cable and turn the power switch to ON. Your macropad is now recognizable as a Bluetooth keyboard in the settings of your autodarts system.

28.
a. Power management note: To preserve battery life, make sure that the device is always turned off via the toggle switch when it is not in use.
b. Charging instructions: To charge the battery, the toggle switch must be in the ON position. When the switch is off, the charging circuit is disconnected and the battery does not receive power from the USB-C port.
c. Battery Life Efficiency: Thanks to the low power consumption of the nRF52840, the battery is designed to last about 6 weeks on a single charge under normal usage conditions.

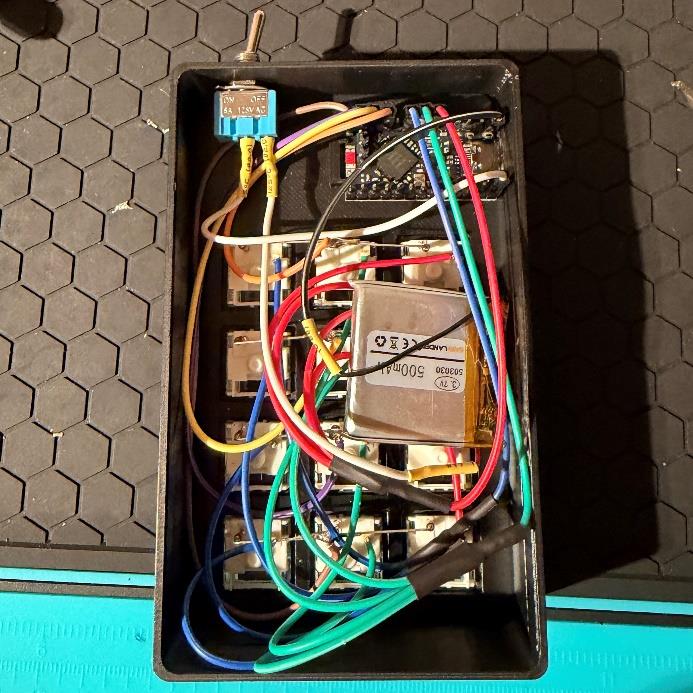
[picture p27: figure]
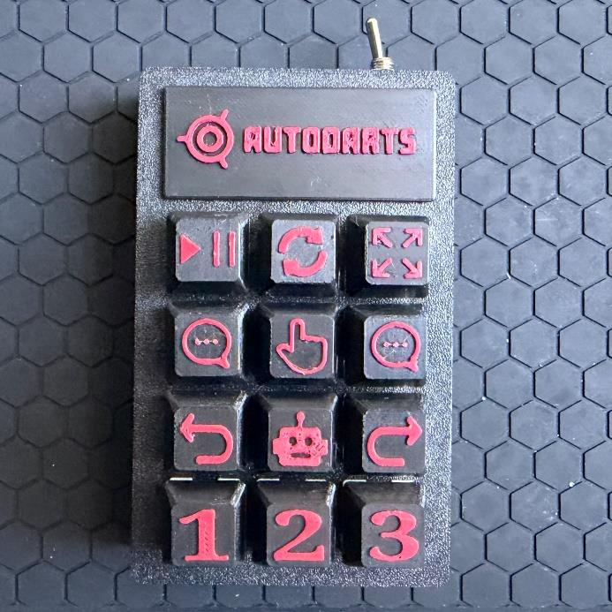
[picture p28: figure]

Author: mrcl-rckl | 23 | Version: 1.0
29. Carefully place the battery in its designated compartment in the case. Make sure all wires are neatly stowed away to avoid getting trapped. Finally, align the back cover and click it in to complete the Autodarts Macropad.
30. Firmly place the 12 keycaps on the switches by pressing them firmly on the keys. Make sure you follow the correct layout order that matches your firmware layout and Autodarts interface.

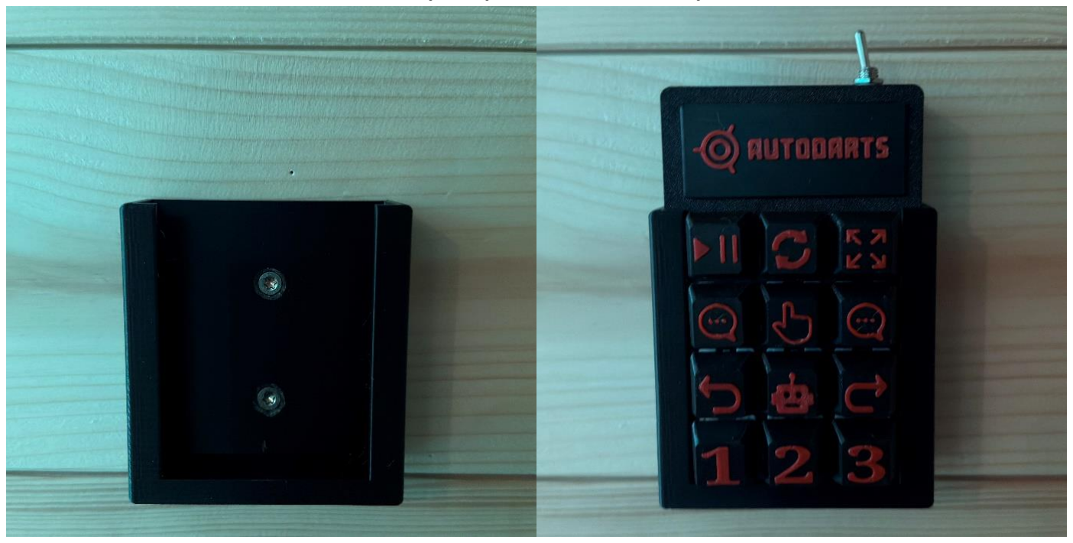
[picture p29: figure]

Author: mrcl-rckl | 24 | Version: 1.0
31. Last but not least: Attach the wall bracket to the wall with the appropriate screws. Once the holder is attached, simply slide the macropad into the holder until it is firmly in place and ready to use.

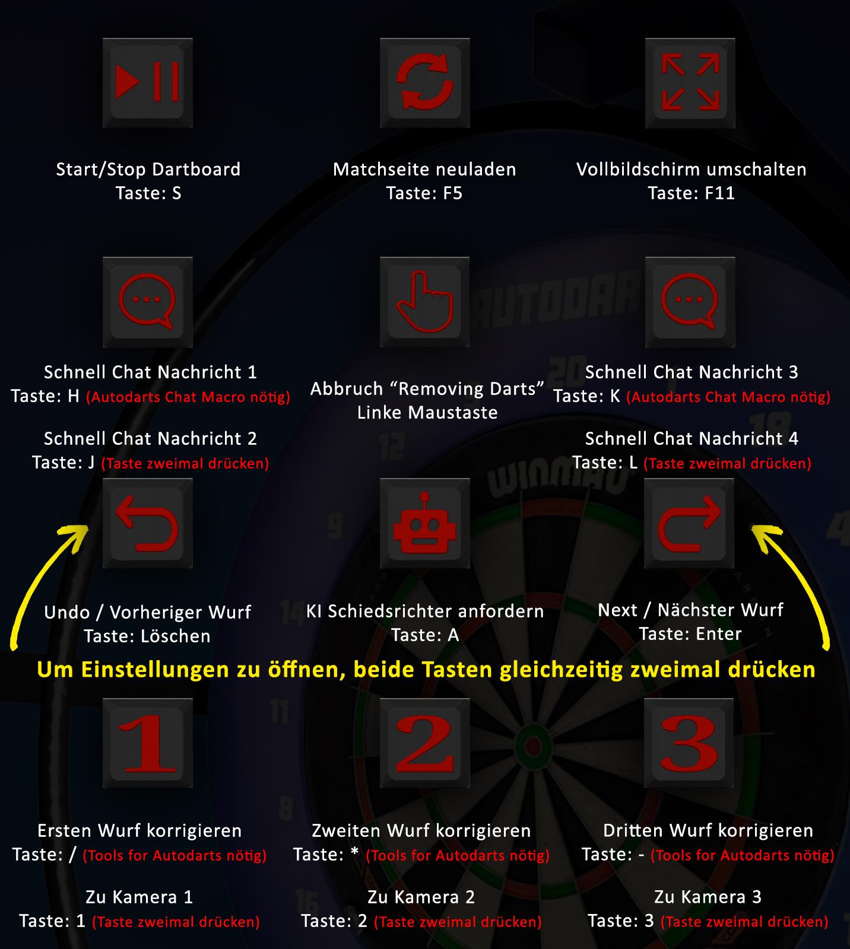
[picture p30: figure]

Author: mrcl-rckl | 25 | Version: 1.0

# Test:

See the following image for the specific key assignments. To check that each key is working correctly and is mapped with the correct command, navigate to the online keyboard tester and press each key on your new macropad: https://www.onlinemictest.com/de/tastatur-test/

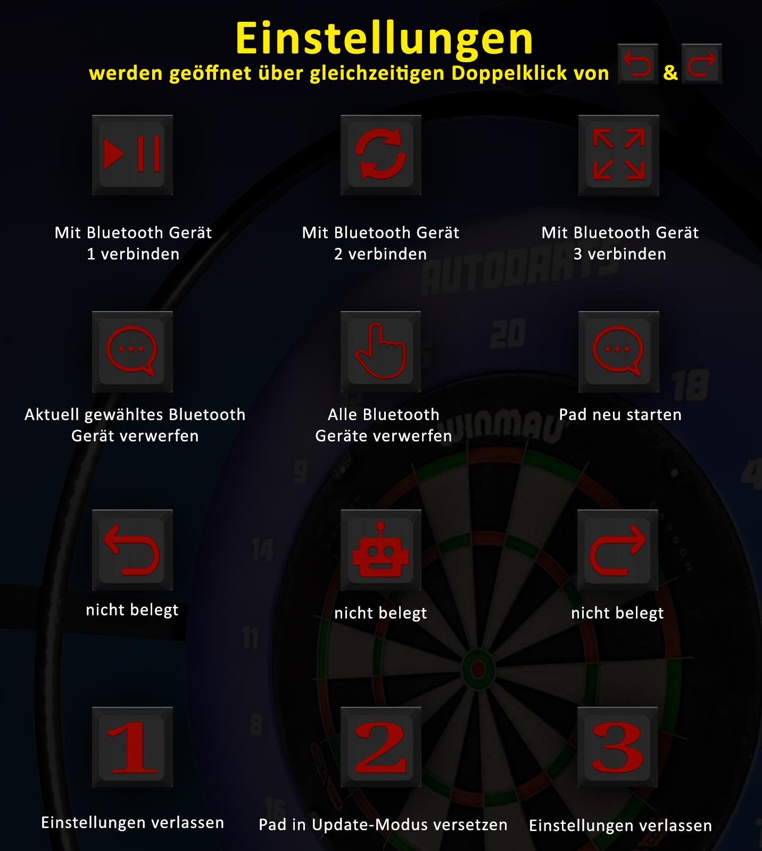
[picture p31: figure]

Author: mrcl-rckl | 26 | Version: 1.0

Author: mrcl-rckl | 27 | Version: 1.0

Author: mrcl-rckl | 28 | Version: 1.0

# Operational Guide:

1. Turning the device on and off: Use the physical toggle switch on the side/back of the case. Power Saving: To maximize battery life, it is recommended to turn off the device when not in use, although the nRF52840 offers a power saving mode in deep sleep mode.
2. Battery level monitoring: The Autodarts Macropad reports its battery level directly to your operating system via the Bluetooth HID profile. You don't have to rely on internal LEDs. On Windows (11/10): Navigate to Settings > Bluetooth and Devices. Find the "Autodarts Macropad" in the list. The battery percentage is displayed right next to the device name. On Linux (GNOME/KDE): Open your System Preferences and go to the Power or Bluetooth section. The battery status is displayed under "Devices" or "Input Devices". Command Line (Advanced): You can also use the upower -e command to find the device path, and upower -i [path] to see the exact percentage.
3. Requirement for charging instructions: The toggle switch must be in the ON position to charge the battery. When the switch is off, the charging circuit is physically disconnected and the battery does not charge via USB-C.
4. Bluetooth pairing and resetting: Since the Macropad can store up to three different devices (e.g. PC, laptop, tablet), connecting and switching is done via the hidden admin level.
To enable admin mode: Make sure the device is ON. Press the [Backspace] and [Enter] keys at the same time twice in quick succession (like a double-click). The pad will now switch to admin mode for 5 seconds. Switch Bluetooth device (Profile 1, 2, or 3): Turn on Admin Mode and press one of the top three buttons (row 1) to switch to Profile 1, 2, or 3. The pad will then automatically connect to the device stored there.
Pair new PC (reset profile): If you want to connect the Macropad to a new computer, you must first delete the currently selected profile to trigger the pairing mode: Activate the admin mode (double-click on Backspace + Enter).

Author: mrcl-rckl | 29 | Version: 1.0

Press the left button in the second row. The device clears its memory for this profile and immediately switches to pairing mode. It will now be discoverable again as a new device in your system's Bluetooth settings.

Author: mrcl-rckl | 30 | Version: 1.0

# Frequently Asked Questions:

Connectivity & Bluetooth:

Q: The connection feels delayed or the buttons repeat.

A: Bluetooth signals can be affected by interference. Make sure there are no large metal objects or powerful 2.4GHz routers directly between the pad and your computer. If you're using a desktop PC, make sure your Bluetooth antenna is plugged in.

Power & Battery:

Q: I've been plugging the pad into USB-C for hours, but the battery is still dead.

A: Crucial control: Is your toggle switch ON? Due to the hardware design, the battery only connects to the charging circuit when the switch is in the ON position. It does not charge when the device is turned off.

Q: The device works via USB, but it turns off immediately as soon as I unplug the cable.

A: Check the solder joints on the B+ and B pins of the microcontroller, as well as on the battery wires. Also, make sure that the wiring of the toggle switch is correct. If a cable has come loose, the battery power supply cannot reach the MCU.

Key Inputs & Hardware:

Q: A certain key is not registered at all.

A: This is usually a hardware problem. Check the solder joints on this exact key. Check the orientation of the diode. If the diode is soldered backwards, the signal will be blocked. Check the connection between the line/column cable and the MCU pin.

Author: mrcl-rckl | 31 | Version: 1.0

Q: When I press a key, the wrong letter appears on the screen.

A: Your physical cabling probably doesn't match the GPIO pins defined in the firmware. Check your wiring again with the wiring diagram on page 20. If you've swapped a row or column cable, the layout will be mirrored or moved.

Firmware & Flashing:

Q: The controller does not appear as "NICENANO" or "Removable Drive" when plugged in.

A: Use a different USB-C cable; Many cables are only on charging cables and do not transmit data. If the cable is fine, you'll need to manually enable bootloader mode.

Q: I flashed the .uf2 file, but nothing has changed.

A: Make sure the file transfer is complete before the drive is disconnected. If the drive disappears immediately after deleting the file, the flash was probably successful. If necessary, the Hard-Reset.uf2 file can be flashed first, which resets the controller. Afterwards, the normal firmware should be flashed again.

Car darts details:

Q: No buttons work within the autodarts interface.

A: Make sure the browser window is "focused" (click in the Autodarts browser window).

Quick Chat Feature:

Q: How do I use the Quick Chat Macros?

Author: mrcl-rckl | 32 | Version: 1.0

A: Make sure that this script "Autodarts Chat Macro" is installed (https://greasyfork.org/de/scripts/562681-autodarts-chat-macro-overlay-panel-v4-93) in
Tampermonkey (download for Chrome here). (https://chromewebstore.google.com/detail/dhdgffkkebhmkfjojejmpbldmpobfkfo) Assign the macros to the H, J, K, and L keys.

Is your problem still not solved? If you've reviewed all of the above steps and the pad is still not working, please visit the GitHub Repository Issues page to report your issue or check for community-contributed solutions!

Author: mrcl-rckl | 33 | Version: 1.0

# Firmware customization:

The Autodarts Macropad is fully customizable. If you want to change the key assignment or add new macros, you can adjust the ZMK firmware. Since the project is hosted on GitHub, you don't need to install any programming tools on your PC – the firmware is automatically created in the cloud.

The configuration of your buttons is stored in the "keymap" file. The original file can be found at this address: https://github.com/mrcl-rckl/autodarts_macropad/blob/main/config/macro12.keymap (https://github.com/mrcl-rckl/autodarts_macropad/blob/main/config/macro12.keymap)

How to change the layout:

- Fork the repository: Go to the main project page: https://github.com/mrcl-rckl/autodarts_macropad. (https://github.com/mrcl-rckl/autodarts_macropad) Click the "Fork" button in the top right corner to create your own copy of the project.
- Edit the keymap: In your forked repository, go to the config/macro12.keymap file and click on the pencil icon to edit the code directly in your browser.
- Change keycodes: Replace the existing commands (e.g. &kp ENTER) by the desired commands.
- Example: To change a mapping to the letter "M", use &kp M.
- Commit & Build: Click on "Commit changes" to save. This will automatically start a build process in the Actions tab of your GitHub repository.
- Download & Flash: Wait about 2-3 minutes. Once the build is complete (marked by a green checkmark), click on it, scroll down and download the firmware. Unzip the file and flash the .uf2 file as described on page 23.

Useful resources:

- ZMK Keycode Reference: A complete list of all available keys (media keys, F-keys, etc.) can be found here: https://zmk.dev/docs/codes

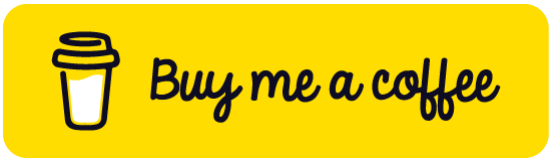
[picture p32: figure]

Author: mrcl-rckl | 34 | Version: 1.0

# Thank you for your donation:

# https://buymeacoffee.com/mrcl_rckl

## If this DIY project hit the mark with you and you liked the building, you are welcome to support my work. Every donation is very welcome and helps me to develop more

open source tools for the community.

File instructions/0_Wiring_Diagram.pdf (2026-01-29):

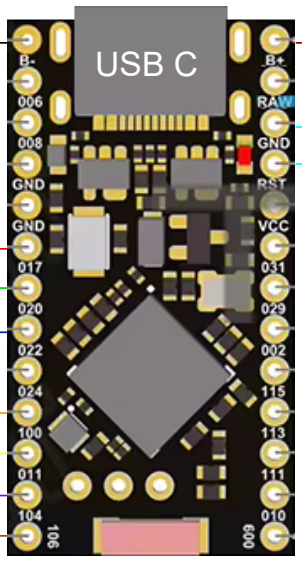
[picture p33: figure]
USB C

Bridge contacts to reset controller and it will enter flash mode
